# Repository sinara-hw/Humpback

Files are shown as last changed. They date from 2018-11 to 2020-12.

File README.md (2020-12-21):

# Humpback
General purpose STM32/ESP32/OrangePi/Beaglebone baseboard with FPGA and 2 downstream / 1 upstream EEM ports

## Design Files

Design files (schematics, PCB layouts, BOMs) can be found at [Humpback/Releases](https://github.com/sinara-hw/Humpback/releases).

## Wiki

More information can be found on the [wiki](https://github.com/sinara-hw/Humpback/wiki).

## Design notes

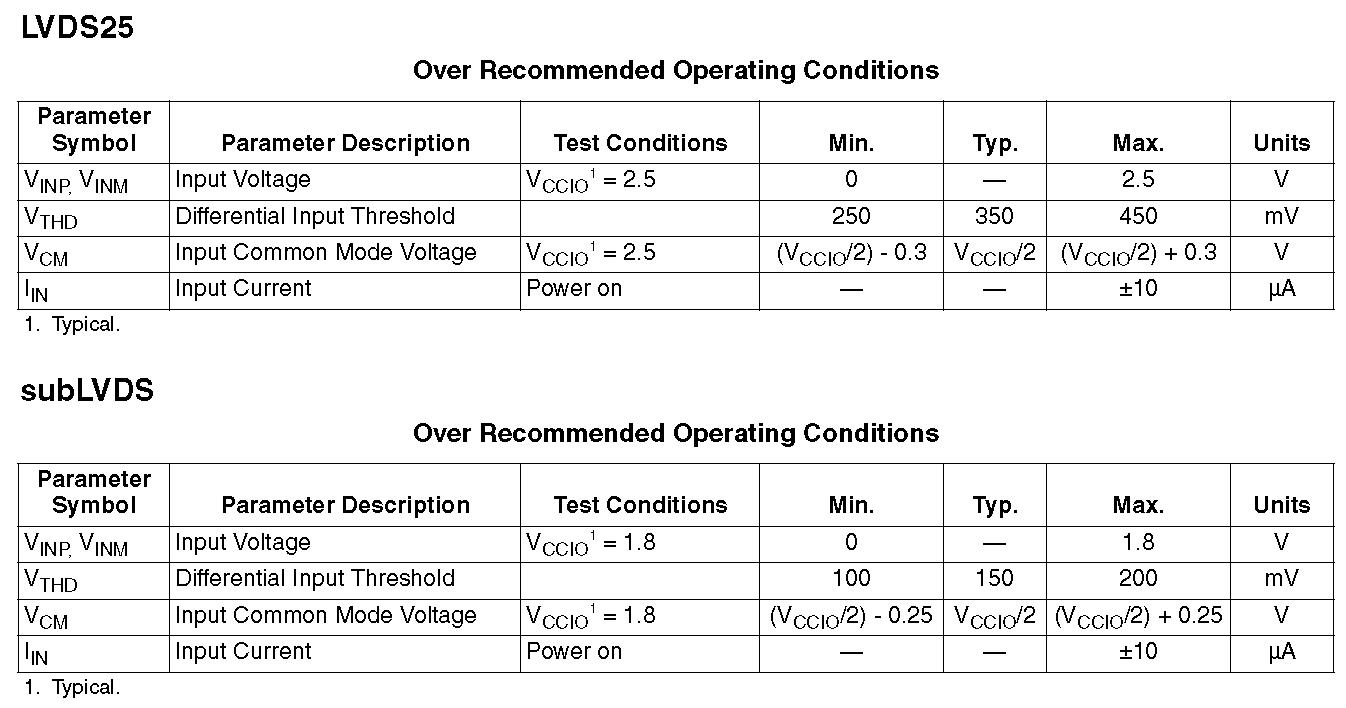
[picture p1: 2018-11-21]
LVDS.PNG

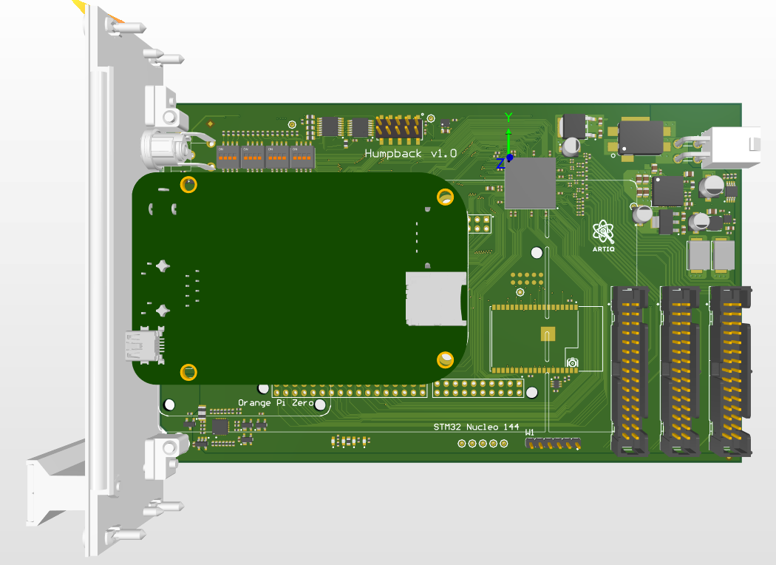
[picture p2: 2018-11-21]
Humpback.PNG

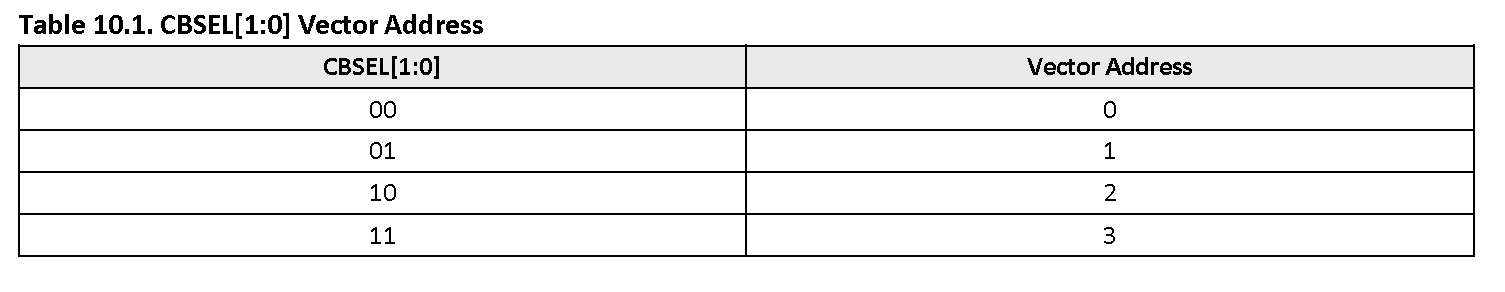
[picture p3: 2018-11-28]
CBSEL.PNG

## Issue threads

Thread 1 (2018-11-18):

[RFC] new EEM: humpback

jordens, 2018-11-18:
Despite the general purpose of the Sinara ecosystem hardware and the wide range of features, lot of development in labs is still based on random "toy"/"development"/"evaluation"/"hobbyist" boards (called "boards" throughout) with µCs and FPGAs. They are dirt cheap, fit for the many applications that lie outside the typical use cases for Sinara EEMs, get the job done just fine, and have a shallow learning curve suitable for physicists. That won't change and there seems no point in trying to replace those "boards". Instead let's try to integrate them.

## Idea

I'd like to propose a simple modification to the [TTL tester EEM](https://github.com/sinara-hw/sinara/raw/master/ARTIQ_ALTIUM/EEMs/Tester/3U_TTL_Tester.PDF) to give it a much wider applicability and open it up for more use cases.

The basic idea is to

1. get connectivity between boards and the Sinara EEM connector
2. build a easy way of mounting those boards in a crate
3. to supply them with power.

## Use cases

* Ethernet connectivity of all kinds. Translate EEM to ethernet.
* Can be get plenty of power from PoE independent of the board (e.g. [21W](https://www.digikey.de/product-detail/en/phihong-usa/POE21-120/993-1080-ND/2384559))
* Wire up microcontrollers that run simple control tasks and loops (temperature control, laser power stabilization, slower modulation/demodulation frequency locks) when (a) where the µC is connected to EEMs and controlling them and (b) when the µC is connected as an EEM to a core device.
* Enable usage and testing of other EEMs with a simple adapter using a µC or FPGA. Also for acceptance testing at the factory.

## Implementations

There seem to be two approaches:

### A EEM adapter: Shield

Build a "shield" that just implements the connectivity aspect (1) where a remote board is connected to the core device.
  * To be used outside a crate
  * 2xRJ45 connected to a DIO-RJ45 EEM in a crate and thus to the core device
  * Should use the same LVDS-to-CMOS converters and DIP switches as Tester. Or maybe just a cheap (ICE40) FPGA (and DIP switches)
  * Should be powered from the board
  * Does not give I2C connectivity.

### A EEM board carrier: Humpback

Build a EEM that achieves (1) both ways, (2), and (3).
  * Call it e.g. "Humpback"
  * Mount the board on the EEM
  * Since there will likely be a need for external connectivity, while the panel pattern for that connectivity is unknown, let's open up the panel and also build a gap into the board so that only a panel frame (or even just a panel-U) remains.
  * Make the EEM short so that small boards can be used and large boards just stick out of the crate.
  * Two EEM connectors
  * Power the board from the EEM
  * Add a barrel connector so that the EEM can power MP3V3, the board and attached EEMs or the EEM and board can be powered from the upstream core device (I.e. dual use just like Tester).
  * Maybe a 5V SMPS for VIN to feed the more [sensitive](https://www.arduino.cc/en/ArduinoCertified/IntelGalileo) boards.
  * Use a cheap FPGA (ICE40 maybe) to convert LVDS. Add DIP switches and implement an I2C direction control shift register in FPGA.
  * Expose 8xCMOS or LVDS raw (for FPGA boards) and I2C to board.
  * Maybe expose MP3V3 to board.

## Potential layouts and pinouts

The choice for the connector layout (power, i2c, digital) is a bit tricky. For both shield and EEM there could be:

### Arduino Uno V3

The "Arduino Uno v3" pattern for the shield and the EEM plus a common denominator of mounting holes and standoffs for the EEM would cover large subset of boards. These are typically stacked and the EEM would probably the "top" of the stack while the board is the "bottom".
Best position and orientation unclear.

µC/CPU:
* [Arduino](https://store.arduino.cc/arduino-due) (*but not with 5V IO!*)
* [ST Nucleo 144](https://www.digikey.com/product-detail/en/stmicroelectronics/NUCLEO-F429ZI/497-16280-ND/5806777), [ST Nucleo 64](https://www.digikey.com/product-detail/en/stmicroelectronics/NUCLEO-F446RE/497-15882-ND/5347712)
* ~[Intel Galileo](https://www.arduino.cc/en/ArduinoCertified/IntelGalileoGen2)~

FPGA:
* Xilinx Artix: [Arty](https://www.xilinx.com/products/boards-and-kits/arty.html#hardware)
* Intel Max 10 (fka Altera) [XLR8](http://www.aloriumtech.com/xlr8-fpga-board/)
* Xilinx Spartan 6: [Papilio (Pro)](http://papilio.cc/index.php?n=Papilio.PapilioPro)
* Lattice ICE40:

### 26 pin Raspberry Pi+

Has 5V, I2C, 3V CMOS, mounting hole pattern.

* Raspberry Pi B+ etc
* [Orange Pi (Zero)](http://www.orangepi.org/orangepizero/)

### Digilent PMOD

Probably only as a shield.

### ST Morpho

* Nucleo

### ST ZIO

* Nucleo 144

### beagle bone

* Beagle bone black

gkasprow, 2018-11-18:
@jordens do you want one of EEM ports to be upstream? I.e. to use one of SBC as a target for Kasli ?

jordens, 2018-11-19:
3d printed panel inserts sounds good. Then you can easily do recessed panels or none at all for quick testing.
Yes. I'd stick pretty close to the banker design for the eem connectors. Using Humpback as a Target for kasli is definitely a nice use case.

gkasprow, 2018-11-19:
I want to produce Humpback, Stabilizer and Banker at the same time using shared documentation to limit NRE costs.
@jordens @hartytp  please check schematics and initial component placement for Humpback. The board is 99% routed but no DRC and cosmetics were done.
PDF is here, sources are in repo
[Humpback.PDF](https://github.com/sinara-hw/Humpback/files/2596750/Humpback.PDF)

I provided support for: Nucleo 144 (compatible with Arduino), Beaglebone Black, Orange Pi Zero, Wiznet (2x UART only) and ESP32 which uses same code and tools as ESP8266 but has 2 CPU cores and much more memory. I use it for my projects since some time. And it has ufl antenna connector for WiFi and Bluetooth so one can attach SMA pigtail to the 3D printed panel and gain wifi access. It is supported by Arduino so remote logging or control using MQTT with i.e. Cayenne/Blynk and mobile App is trivial - just a few lines of code. I have such projects in my private repo.
All common ports like I2C, UARTs, SPI were routed together to save pins.
All SBCs have access to FPGA configuration pins so they can load the FPGA directly without supporting FLASH. There are open source codes that do it for Beaglebone and STM32.
Beaglebone pin naming comes from LOGI-BONE project where bus access to FPGA is uses. I also use same FPGA config pins so changes to the code would be minimal. Open source HDL and Linux code are available. Rest of Beaglebone pins are named as GPIOs
All dedicated pins were connected to individual FPGA pins. In this way we will be able to provide and support same HDL code for all SBC platforms.

hartytp, 2018-11-19:
@gkasprow I'm not really the best person to review this kind of design. I had a quick look over it and it looks really nice, but I can't give you detailed feedback (not enough experience using these kind of microprocessor boards).

One question: did we plan to make this a PoE module? Or, is it intended to always be powered from a 12V supply?

hartytp, 2018-11-19:
> I want to produce Humpback, Stabilizer and Banker at the same time using shared documentation to limit NRE costs.

Can we sneak Thermostat in there as well?

jordens, 2018-11-19:
A quick first set of comments:

* Great work. Congrats to fitting all devboards onto Humpback! I didn't expect that.
* I assume this would come with all pin headers not soldered but still included.
* It's a bit risky to do all three boards at the same time especially with Banker and Humpback being so similar. Fine if the NRE savings outweigh that risk.
* Testpoints should be on the top if at all possible (TP*, B*)
* Nice solution on the I2C master/slave issue! I also extended the kasli-i2c tools to automatically scan any tree configuration of those I2C switches recursively. I.e. EEPROM detection is fine at any depth.
* The Nucleo 144 boards seem to have one of four different pinouts. But I couldn't identify the actual difference quickly. Which pinout is this?
* Is that distance between the capacitor/resistor combo and the front panel screws/washers large enough?
* Doesn't the ESP32 need a specific ground/keep-out area/pattern near the PCB antenna?
* From the PCB renders with the 12V copper areas, the EEM headers are still the wrong assignment. The upstream one should be the rightmost.
* Is 10µF as the biggest cap going to be sufficient for the FPGA VCC/VCCIO? Comparing that with Kasli it sounds tiny. But I guess you took a devboard as the reference.
* I didn't check any pinouts, or pins vs datasheet consistency. Would you like someone to do that?
* No PoE is fine by me. There are cheap external PoE+ splitters for barrel.

gkasprow, 2018-11-19:
>
>     Great work. Congrats to fitting all devboards onto Humpback! I didn't expect that.
>     I assume this would come with all pin headers not soldered but still included.

yes
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
jordens, 2018-11-21:
All ACK.
I'd like to be able to use the STM32 ADC/DAC without worrying about the FPGA pins connected to them. Let's put 0R (or a DIP switch array? but I am fine with 0R here) on PA3 PC0 PC3 PC1 PC4 PC5 and PB1 PC2 PA2 for ADC and PA4 PA5 for DAC.

jordens, 2018-11-21:
And it would be great if the various switch and pin arrays could get lots of silkscreen labels, even for individual pins on the PCB top side.

jordens, 2018-11-22:
Looking at the [ice40hx break out board](https://www.latticesemi.com/view_document?document_id=50373) and the [ice40 hardware checklist](http://www.latticesemi.com/-/media/LatticeSemi/Documents/ApplicationNotes/IK/iCE40HardwareChecklist.ashx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). Probably also applies to Banker.
* The FPGA gets a 100n for each supply pin
* 10u for VCCPLL1 and 0
* You decided that LDOs to get from 5V to 1.2 and 2.5V is efficient enough and not switchers are needed?
* They have 10n and 1u on a couple of rails but I don't know whether that makes much sense. THey don't have your 100p though.
* N14 on the FPGA is TRST_B on that devboard and pulled low. Also mentioned explicitly in the HW checklist.

gkasprow, 2018-11-22:
I copied it from working design. And that working design was copied from somewhere else. So errors could propagate.
I can add switcher for 1.2V, but for such small FPGAs I expect core current less than 0.5A.
We can use same low cost AUR9705 chip as for 3.3V

jordens, 2018-11-22:
ACK, I am not particularly worried about LDO vs switcher and my guess is significantly less than 0.5A but that would be 1W burned in the LDO.

gkasprow, 2018-11-23:
I didn't finish the mechanical side yet. True, we will need Ethernet cutout to use stadard goldpin connectors.

gkasprow, 2018-11-23:
Lattice is using 300mA LDO (LT3030EFE#TRPBF) on their ICESTICK devkit which uses  HX4K FPGA They supply it from 5V directly.

gkasprow, 2018-11-25:
OK, I used switcher. It costs 0.5EUR.

jordens, 2018-11-27:
@gkasprow Thanks for the new RC. A few things left from above. Ignore if you are already aware.
> * I'd suggest connecting GBIN0 to SPI_SCK (clock FPGA from CPU SPI) and GBIN1 to STM32_PB10 or STM32_PB11 (clock FPGA from CPU timer), GBIN4 and 5 are good.
> * Beefing up/bypassing of the downstream EEM fuses
> * RJ45-PCB interference and beaglebone mounting?

* On Humpack the front panel screw RC combo is now nicely clear of the screw/washer. Should that also be implemented for Banker?

gkasprow, 2018-11-27:
@jordens there is no place for RJ45 cutout. It collides with other board connector. Let's use longer headers.
Bypassing EEM fuses can be good idea. It will simplify layout and improve SI of LVDS lines.

jordens, 2018-11-27:
Yes. Let's skip the eem fuses on Humpback Altogether. Ack the longer headers for beahlebone. does it also apply to orange pi zero?

gkasprow, 2018-11-27:
Orange pi has no connector soldered by default so standard pins would work.

jordens, 2018-12-02:
The stackup has a 0,71mil dielectric between Top and Gnd layers. I hope that's a typo.

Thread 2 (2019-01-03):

cPCI S.0 backplane support

jordens, 2019-01-03:
Lower prio than the other boards and it might be a bit tight on space. But it would be nice.

https://github.com/sinara-hw/Banker/issues/3
https://github.com/sinara-hw/Stabilizer/issues/5

Closed 2019-01-10.

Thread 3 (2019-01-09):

panel

gkasprow, 2019-01-09:
@jordens Please have a look at the panel
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

jordens, 2019-01-10:
Ok. Nice.
* I guess the screw holes are for mounting the panel insert, right?
* What about removing the panel "bar" at the top (right side when in the crate)? Then a front panel could extend beyond 8 HP and would already be mechanically fixed to Humpback.

gkasprow, 2019-01-10:
Yes, they are for fixing the panel insert. I can remove the panel bar, but I'm afraid it won't be rigid enough and bend. Why do you want to extend beyond 8HP?

jordens, 2019-01-10:
To expose e.g. the µC ADC and DAC channels on the front panel. But you are probably right, that's not particular rigid, the use cases for raw ADC and DAC channels are few and if needed one coule hack up a quick 3U raster board, some jumper cables and connectors with its own panel.

jordens, 2019-01-11:
@gkasprow I think the panel might be covering the edge LEDs on the underside of the board. Add holes?

Closed 2019-01-10.

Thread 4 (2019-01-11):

[I2C switch] move TEMP to port 0 (with EEPROM) and put EEM2 on port 5

jordens, 2019-01-11:
same as https://github.com/sinara-hw/Banker/issues/5

gkasprow, 2019-01-11:
in Humpback we already have EEM2 I2C on port 4.

jordens, 2019-01-11:
Oh. I had overlooked that. All good then.

Closed 2019-01-11.

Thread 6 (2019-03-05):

Humpback tests

gkasprow, 2019-03-05:
Humpback arrived!
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

gkasprow, 2019-03-06:
power supply works fine after R166 fix

gkasprow, 2019-03-07:
LED blinks, FLASH works
I used [same FPGA](https://github.com/sinara-hw/Banker/issues/8) project as for Banker

jordens, 2019-03-13:
Also works fine mechanically and electrically with a Nucleo144 STM32F429 and ethernet.

jordens, 2019-03-13:
* I'd add the headers for the boards to the BOM but not mounted, just shipped.
* Make the panel cutout 0.5 mm wider. The nucleo barely fits.
* I would not mount the ESP32 by default. It's a bit tricky to remove.
* Also on the ESP32, I think that's the version with the wifi signal connected to the u.fl connector and not to the PCB antenna by default. IMO that's ok but **if** there is a ESP32 mounted, there should be a pigtail antenna.
* JP2 and W1 should get silkscreen labels.

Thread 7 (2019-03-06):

Humpback errata

gkasprow, 2019-03-06:
Pull R166 to P12V0 instead of P3V3

kaolpr, 2020-05-21:
@gkasprow What do you mean by "add R to GND"?

gkasprow, 2020-05-21:
@kaolpr just make voltage divider between 12V and GND that gives 3.3V.
For the moment, to fix v1.0 remove R160 and connect pin 38 of IC87 via 10k to +12V
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

In the next revision make sure IC2 and IC3 are supplied from 12V via parallel Zener-based regulator.

gkasprow, 2020-05-21:
For rev 1.0 just cut the polygon and connect the LDO input to 5V rail
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

gkasprow, 2020-05-21:
Optionally, one can lift pin 3 of IC4 and connect it to C244 without cutting the polygon.

jordens, 2020-05-21:
@kaolpr  is this for a new batch of v1.0 or a new revision?

gkasprow, 2020-05-21:
TS produced more v1 boards and need to implement these fixes manually

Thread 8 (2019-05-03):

Serial pinout

airwoodix, 2019-05-03:
As discussed in m-labs/migen#180, the pinout and schematics indicate the serial wire names from the µC perspective. Should at least the netlist be changed to reflect the FPGA perspective?

jordens, 2019-05-03:
The decent solution is probably: The net should be called cpu_tx or fpga_rx and then the fpga platform can call it rx and the CPU code can call it tx.

airwoodix, 2019-05-03:
Of course, `cts` and `rts` need to be crossed as well.

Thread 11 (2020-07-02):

Bottom part of STM32 nucleo blocks downstream0 port

occheung, 2020-07-02:
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

gkasprow, 2020-07-03:
Just solder correct stacking height connectors! This boards was not supposed to be plugged directy.

sbourdeauducq, 2020-08-12:
Do you have part numbers for suitable connectors? With "regular" ~1cm ones, the Nucleo board can be mounted but the EEM connector is obstructed.
BTW this is less of a problem for Nucleo h743zi (as opposed to h743zi2) since the JTAG module can be detached on h743zi.

gkasprow, 2020-08-12:
I'm using elevated connectors for boards plugged to RPI: BSSH-113-D-10-G or ESW-113-23-S-D

gkasprow, 2020-08-12:
they mate with standard female 2.54 sockets

sbourdeauducq, 2020-08-13:
Ordering:
* 16 pins: Mouser No:200-ESW10823GD; Mfr. No: ESW-108-23-G-D
* 20 pins: Mouser No:200-ESW11023GD; Mfr. No: ESW-110-23-G-D
* 30 pins: Mouser No:200-ESW11523GD; Mfr. No: ESW-115-23-G-D
* 34 pins: Mouser No:200-ESW11723GD; Mfr. No: ESW-117-23-G-D

sbourdeauducq, 2020-09-01:
OK, this works. Please close

gkasprow, 2020-09-01:
I will add the info to the schematics

Closed 2020-09-01.

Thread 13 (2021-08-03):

PCB Silk Label Mistakes

Zheng-Jiakun, 2021-08-03:
There are two mistakes on the silk label on PCB FPGA/Flash Programmer Connector (JP1).

1. On the schematic, JP1 Pin 6 is connected to P3V3, while on PCB, the silk shows P2V5.
2. On the schematic, JP1 Pin 2 is FPGA_SDO and Pin 3 is FPGA_SDI, while on PCB, the silk label just interchanges them (Showing Pin 2 is SDI, Pin 3 is SDO).

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

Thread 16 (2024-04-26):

EEM0 collides with recent Nucleo-144 boards

airwoodix, 2024-04-26:
On recent Nucleo-144 boards, the STLINK programmer is not detachable anymore and thus overlaps with EEM0.

With standard-height pin-headers, the port is not usable anymore:

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

Using higher pin-headers is possible, but quickly shifts the board out of the front-panel cut-out.

Would a long version (same as Kasli2/Kasli-SoC) of the board be feasible, to get the full-size Nucleo-144 board not collide with the EEM0 port?

Potentially in combination with #15, would that allow for an extra EEM port on this board?

gkasprow, 2024-05-04:
sure, we can do it in DIOT/EEM form factor.

airwoodix, 2024-05-06:
Sounds great, thanks for the feedback!

Concerning DI/OT: how many ports could fit on this board? 4 DI/OT + 4 EEM sounds like a lot, doesn't it? Since EEM is still more common at the moment, our near term preference would be on more EEMs, but it would of course be nice to have the same level of connectivity with DI/OT.

Are there plans to work on a new Humpback revision in the short/mid-term? I see that there are also a couple of issues with the BOM. It would be nice to consider #15 as well, if that's realistic. Please let us know if we can help.

Thanks!

gkasprow, 2024-05-07:
DIOT and EEMs use same FPGA lines.
What is the exact use case for this board?

airwoodix, 2024-05-07:
[humpback-dds](https://git.m-labs.hk/M-Labs/humpback-dds) is a typical use case, potentially combined with other `DIO` cards. Maybe it could also be used instead of an Arduino for GPS locking of [Wenzel_ref](https://github.com/sinara-hw/Wenzel_ref)?

I was wondering whether 4 DI/OT and 4 EEM connectors would fit on the board, together with the larger footprint for the Nucleo board.

Are there known use-cases for the other supported µC modules (OrangePi, BBB, etc.)? Given the synergy with e.g. Stabilizer and Thermostat, we could envisage a Humpback with a hard-wired STM32H7(53?). But it's more complexity.

gkasprow, 2024-05-08:
So it works as a crate controller?

airwoodix, 2024-05-08:
Yes.

gkasprow, 2024-05-08:
So there is no reason to make it DIOT compatible. We already have DIOT controller with STM32 and ECP5.

airwoodix, 2024-05-08:
Do you mean [STM_Sys_Board](https://github.com/sinara-hw/STM_Sys_Board)? I overlooked that, sorry.

At the moment, the modules we control/want to control are Urukul, DIO_*, maybe Wenzel_ref, which would still require EEM, wouldn't it?

Could one have a variant of STM_Sys_Board with EEM instead of DI/OT instead of a rework of Humpback?
